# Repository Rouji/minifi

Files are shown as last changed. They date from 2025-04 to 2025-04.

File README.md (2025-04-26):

# minifi

Fork of the [chocofi](https://github.com/pashutk/chocofi) for Choc Mini (PG1232) through-PCB switches.

Photo of the backside of the PCB showing the switches sticking through it
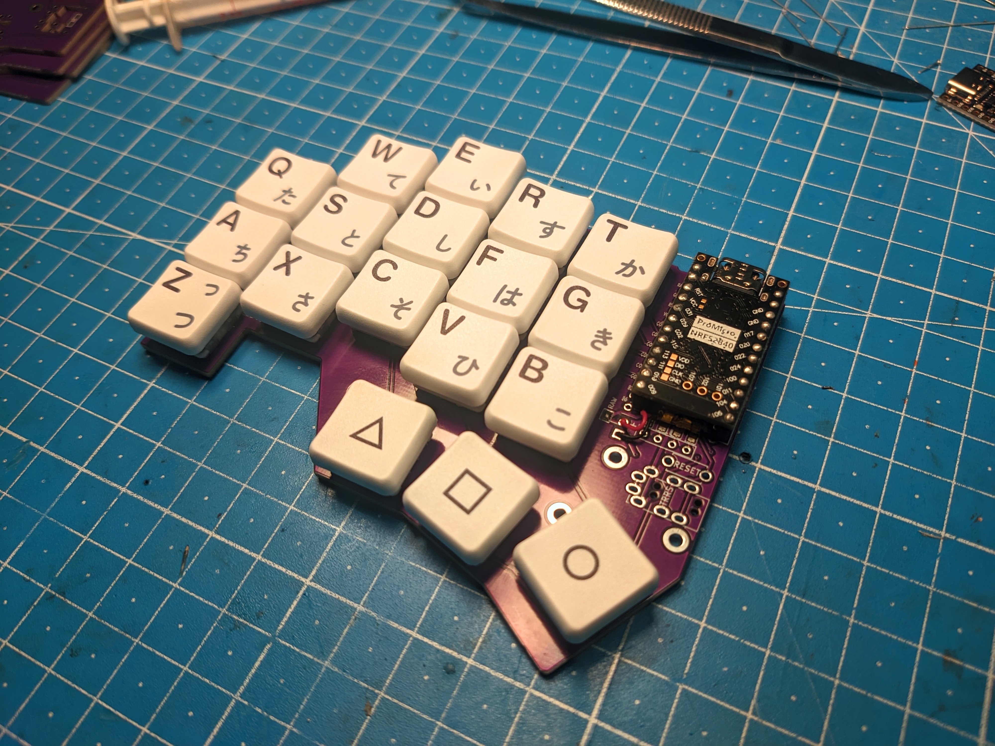
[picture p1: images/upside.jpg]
Photo of one keyboard half from the top


Otherwise basically the same as the chocofi, except I'm pretty sure the case won't fit this anymore. (I haven't tested it though)

# Artifacts

Gerbers are in the [GitHub releases](https://github.com/Rouji/minifi/releases)

# Firmware

The chocofi is wired like a corne, and uses firmware built for the "corne" shield (at least for ZMK).  
Though re-routed, wiring is identical to the chocofi, so you building firmware for this is the same.  

**Note:** The corne has an extra pinky column, so you need to write your keymap as if those columns were there, and they just get ignored. 

# By the way

Recommended batteries:

- [Nice nano docs](https://nicekeyboards.com/docs/nice-nano/#recommended-batteries-and-sockets) explains some basics
- [nRFmicro wiki](https://github.com/joric/nrfmicro/wiki/Batteries#301230) contains links to Aliexpress

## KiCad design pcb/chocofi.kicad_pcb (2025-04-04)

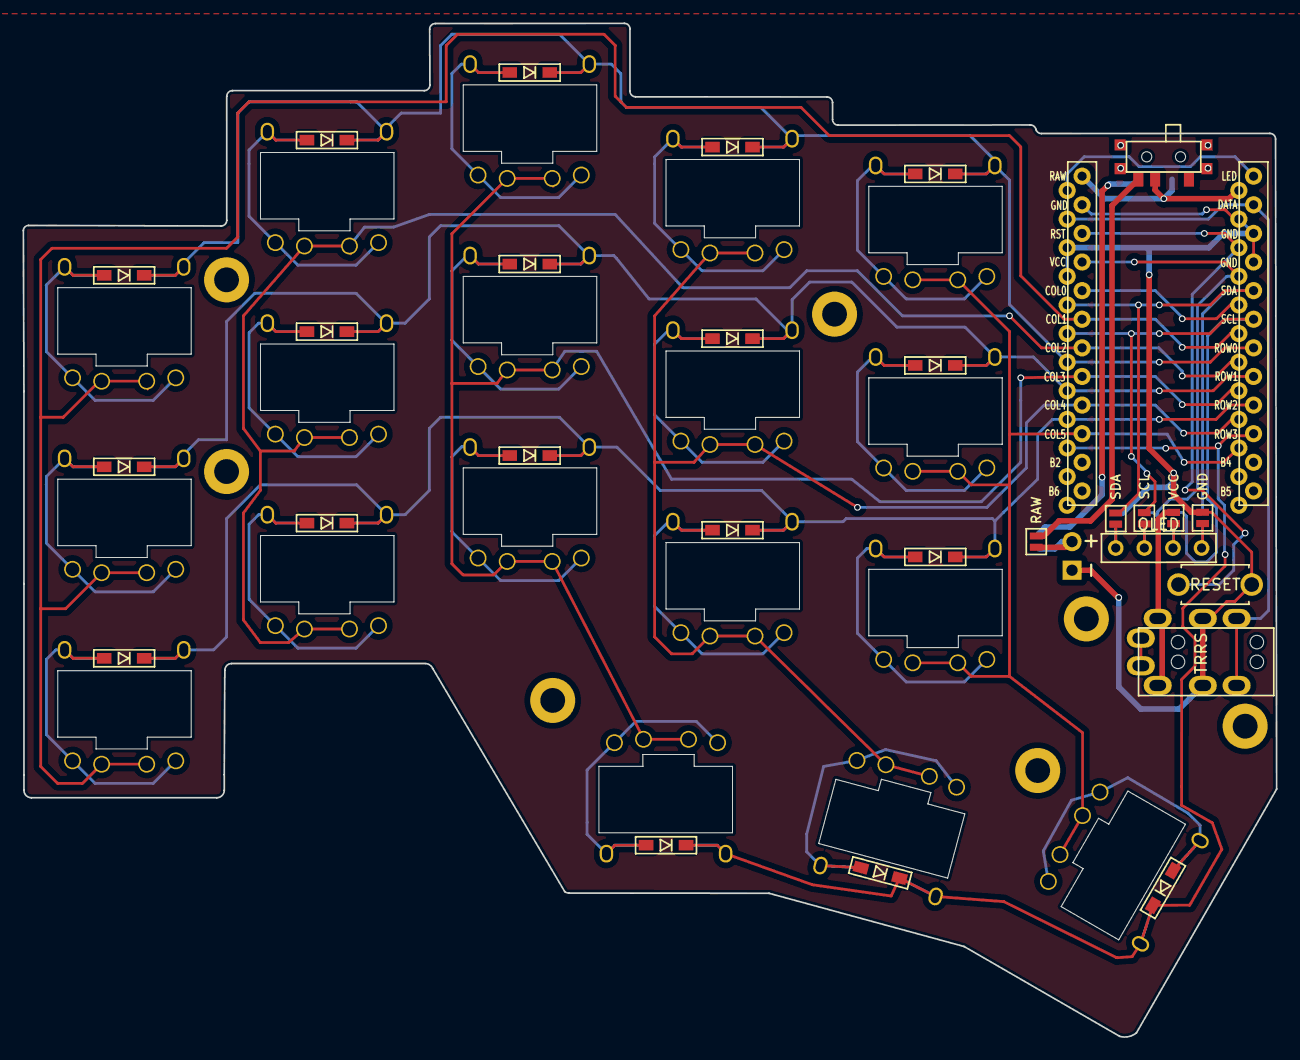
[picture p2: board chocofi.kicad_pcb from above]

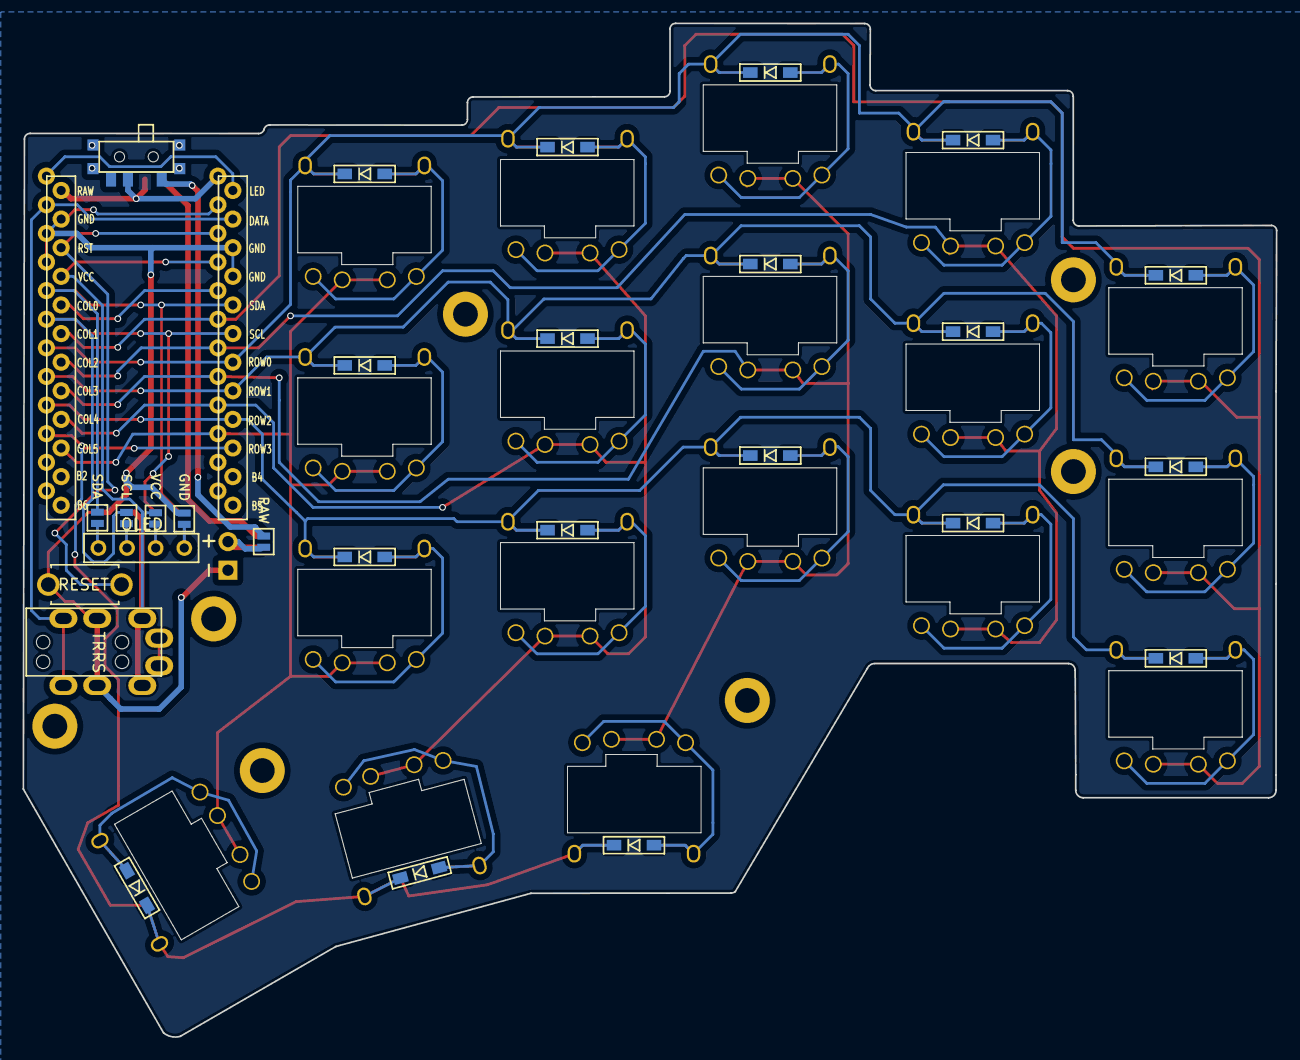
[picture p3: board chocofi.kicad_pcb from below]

Board: 2 copper layers, 111.3 x 90.0 mm, 60 parts (23 on the bottom side), 40 nets.

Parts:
D2, D3, D4, D5, D6, D8, D9, D10, D11, D12, D14, D15, D16, D17, D18, D19, D20, D21: D; D3_TH_SMD
H1: h1; LEGO_HOLE
J1: MJ-4PP-9
J2: OLED
J3: Conn_01x02_Female; Battery_TH
JP6, JP61: SDA; Jumper
JP61#2, JP62#2: RAW; Jumper
JP62, JP68: GND; Jumper
JP63, JP66: SCL; Jumper
JP64, JP65: VCC; Jumper
RSW1: Val**; ResetSW
SW1, SW2#2: SW_SPDT; SW_SPDT+H-MSK12C01_hor(7pin_SMD)
SW2, SW3, SW4, SW5, SW6, SW8, SW9, SW10, SW11, SW12, SW14, SW15, SW16, SW17, SW18, SW19, SW20, SW21: SW_PUSH; SW_Kailh_Choc_Mini_1.00u_reversible
U1: ProMicro; ProMicro_v2
h2: h2; LEGO_HOLE
h3: h3; LEGO_HOLE
h4: h4; LEGO_HOLE
h5: h5; LEGO_HOLE
h6: h6; LEGO_HOLE
h7: h7; LEGO_HOLE

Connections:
BAT_PLUS: J3.2, JP61#2.2, JP62#2.2
GND: J1.C, J3.1, JP62.1, JP68.1, RSW1.1, U1.3, U1.4, U1.23
unnamed: D2.2, SW2.2
unnamed: D3.2, SW3.2
unnamed: D4.2, SW4.2
unnamed: D5.2, SW5.2
unnamed: D6.2, SW6.2
unnamed: D8.2, SW8.2
unnamed: D9.2, SW9.2
unnamed: D10.2, SW10.2
unnamed: D11.2, SW11.2
unnamed: D12.2, SW12.2
unnamed: D14.2, SW14.2
unnamed: D15.2, SW15.2
unnamed: D16.2, SW16.2
unnamed: D17.2, SW17.2
unnamed: D18.2, SW18.2
unnamed: D19.2, SW19.2
unnamed: D20.2, SW20.2
unnamed: D21.2, SW21.2
unnamed: J2.3, JP65.2, JP66.2
unnamed: J2.4, JP6.2, JP68.2
unnamed: J2.2, JP63.2, JP64.2
unnamed: J2.1, JP61.2, JP62.2
unnamed: SW1.2 (B), SW2#2.2 (B), U1.24
SCL: JP63.1, JP66.1, U1.6
SDA: JP6.1, JP61.1, U1.5
SW_RAW_2: JP61#2.1, SW1.3 (C)
VCC: J1.D, JP64.1, JP65.1, U1.21
col1: SW2.1, SW8.1, SW14.1, U1.19
col2: SW3.1, SW9.1, SW15.1, U1.18
col3: SW4.1, SW10.1, SW16.1, SW19.1, U1.17
col4: SW5.1, SW11.1, SW17.1, SW20.1, U1.16
col5: SW6.1, SW12.1, SW18.1, SW21.1, U1.15
data: J1.B, U1.2
reset: RSW1.2, U1.22
row0: D2.1, D3.1, D4.1, D5.1, D6.1, U1.7
row1: D8.1, D9.1, D10.1, D11.1, D12.1, U1.8
row2: D14.1, D15.1, D16.1, D17.1, D18.1, U1.9
row3: D19.1, D20.1, D21.1, U1.10

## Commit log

2024-09-23 swap switch footprints for choc mini ones + reroute
    [chocofi.kicad_pcb]
2024-09-23 rm gerber stuff
    belongs in releases, not the repo
    [chocofi-B_Cu.gbl, chocofi-B_Mask.gbs, chocofi-B_Paste.gbp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]
2025-04-04 remove diode through-holes, move diode pads to led-hole
    through hole diodes obv. don't fit on the side the switches are on,
    and are taller than the feet on the other side.
    we're looking for thinness here, so through-hole diodes are out
    moved the diode pads so the (smd) diodes sit in the void choc minis have
    for LEDs
    also using the adjacent foot through-holes of the switch as a via for
    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
    [chocofi.kicad_pcb]
2025-04-26 swap out images, rm case, update readme
    [bottom.step, top.step]
